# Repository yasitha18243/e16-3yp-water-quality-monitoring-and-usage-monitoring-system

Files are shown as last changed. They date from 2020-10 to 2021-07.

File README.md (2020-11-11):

# Water Quality Monitoring And Usage Management System
In this project we are developing a water tank monitoring system for providing clean water and reduce the water wastage..see our website https://cepdnaclk.github.io/e16-3yp-water-quality-monitoring-and-usage-monitoring-system/

Group No :13<br/>
E/16/049          Harshana Bandara              e16049@eng.pdn.ac.lk           
E/16/134          Yasitha Herath                e16134@eng.pdn.ac.lk                 
E/16/388          Thushara Weerasundara         e16388@eng.pdn.ac.lk   

# Problem

Water mismanagement and consumption of poluted water is a major challenge, the world is facing currently. Current market is yet to address this issue with an effective solution. The solutions that are currently present on the market are either too expensive for domestic usage or does not meet the user expectations.

# Solution

To overcome these issues, we are propossing a device which can be used to measure the water quality of the inlet of a water tank and the water level inside the tank. We expect to target both domestic user requirments and industrial user requirements by a reasonable price. User can control the device using a mobile application.

## 1.	Water quality monitoring

* TDS count – by electric conductivity of water
* Turbidity – by measuring scattering of light in water

For these 2 measurments, TDS sensors and Turbidity sensors will be used and their readings will be analyzed with ideal water quality levels and determine the water quality of the incoming water to the tank during a filling and notify the user if there is any contamination in the water. We use these 2 sensors because by using these 2 readings we can determine most of the characteristics of water.

## 2.	Water level monitoring

By using an ultrasonic sensor, water level will be monitored and when the tank is nearing to finish filling, user will be notified. We use ultrasonic sensor because of it's high accuaracy and sensor is not easily effected by water.
Also this will generate the usage reports of the water and allow user to observe the current water level in the tank if needed. This measurement also allows to rationing of water and user will be warned in case of overusage.

# Overview

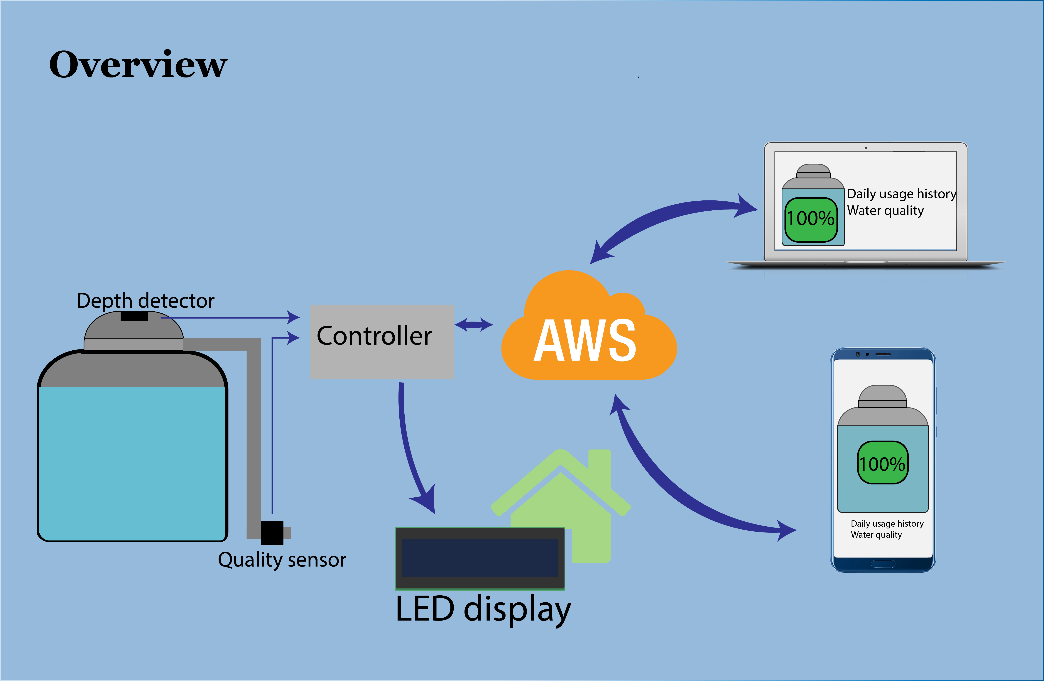
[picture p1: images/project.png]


# Technologies

* AVR       - AVR has a faster execution time than arduino. That will improve the reaction time of the device.
* Flutter   - For mobile application we expect to use Flutter because it is compatible with both ios and android platforms.
* mongoDB   - Since our device is based on cloud computing, mongoDB is the best choice for a database implementation.
* AWS       - AWS offers us higher security and also offers us with variety of IT services.

## [Introductory Video](https://github.com/cepdnaclk/e16-3yp-water-quality-monitoring-and-usage-monitoring-system/blob/main/video/Water%20Quality%20Monitoring%20and%20Usage%20Monitoring%20S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)

# Advising Lecturers

   1. Dr. Isuru Navinna
   2. Dr. Ziyan Marikkar

# [University Of Peradeniya](https://www.pdn.ac.lk/uop/directory/index.php)

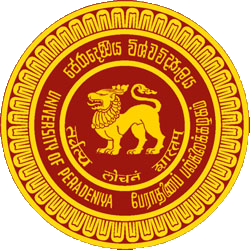
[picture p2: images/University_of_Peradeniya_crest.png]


# [Faculty Of Engineering](http://eng.pdn.ac.lk/)

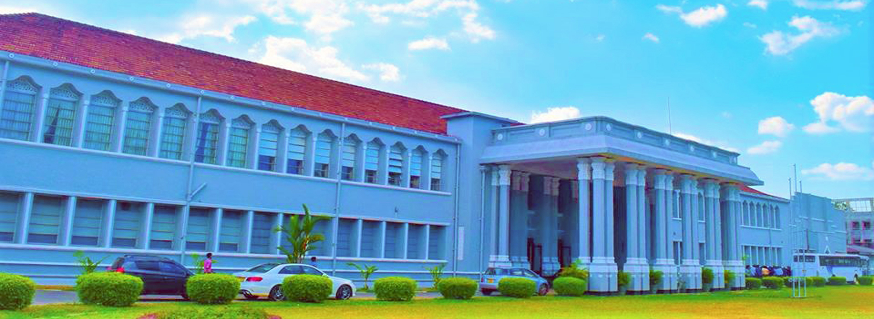
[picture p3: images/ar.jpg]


# [Department Of Computer Engineering](http://www.ce.pdn.ac.lk/)

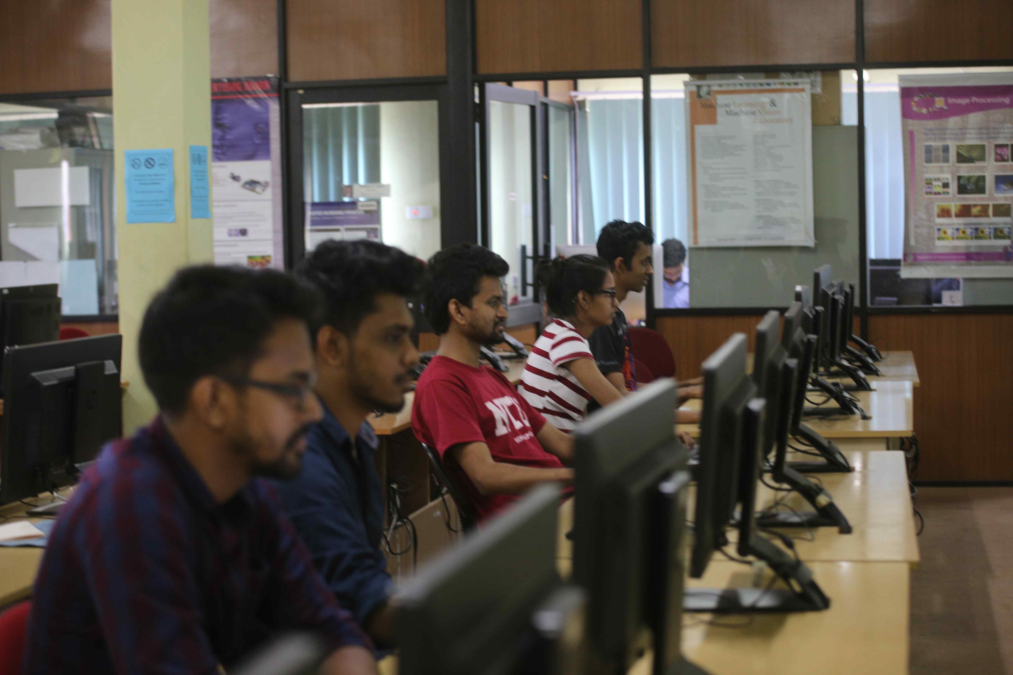
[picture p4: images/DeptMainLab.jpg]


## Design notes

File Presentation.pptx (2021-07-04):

## Water Quality Monitoring and usage monitoring System

Milestone 5 (Group 13)

E/16/049 Harshana Bandara
E/16/134 Yasitha Herath
E/16/388 Thushara Weerasundara

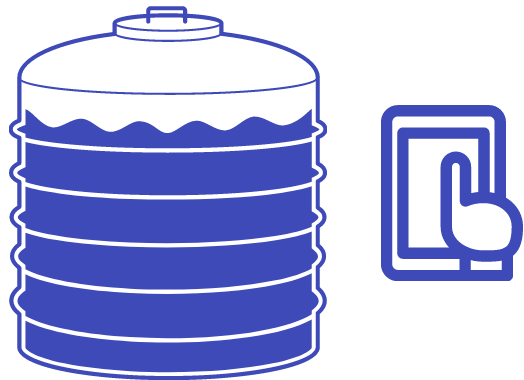
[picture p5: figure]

1

## Review

- Mointor the water level of water tanks
- Monitor the water quality of the filling water of the tanks.
- The required notifications are generated.
Consists of,
- Sensor devices
- Database
- Server

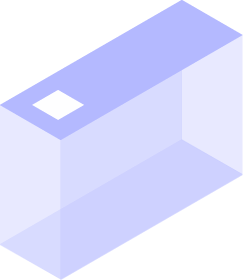
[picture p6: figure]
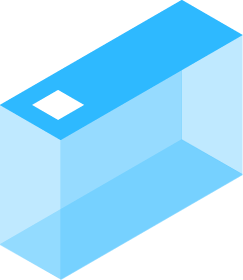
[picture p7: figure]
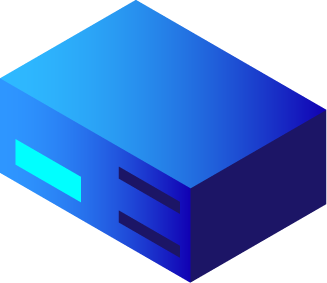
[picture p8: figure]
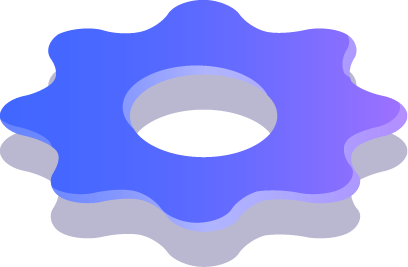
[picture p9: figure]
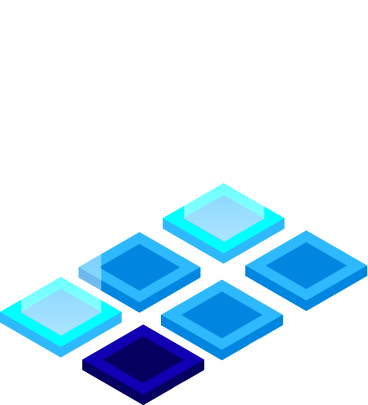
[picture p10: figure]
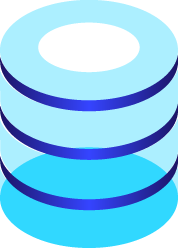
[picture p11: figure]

2

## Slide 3

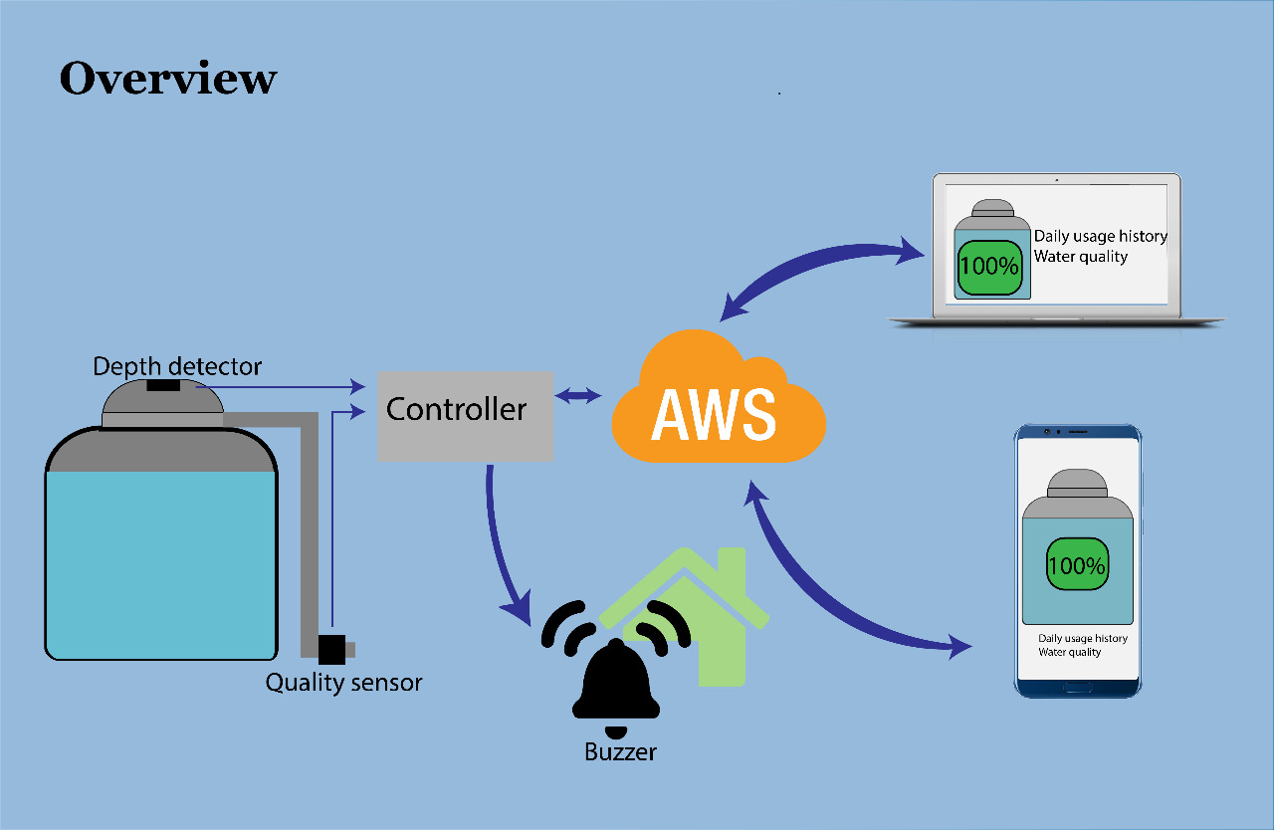
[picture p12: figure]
WhatsApp Image 2021-03-09 at 23.26.36

3

## Roles of the system

User

- Monitor Devices and Receive notifications

Admin

- Monitor the system
- Customer management and support

Super Admin

- Manage Admins

4

## Cloud Deployment

- Node js server -
EC2 instance
NGINX reverse proxy
Firewall protection
- Mongodb database
Keeping snapshots for
backup data

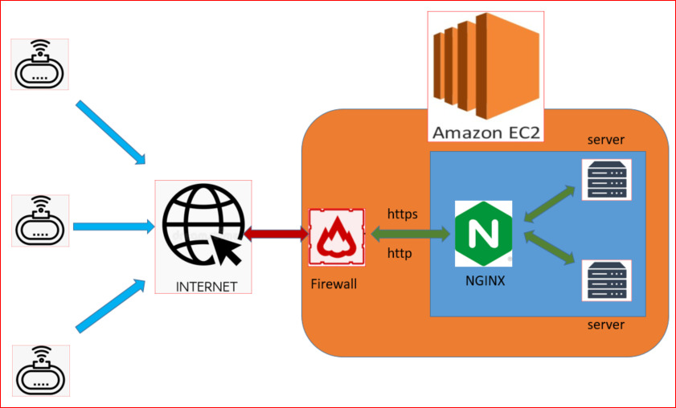
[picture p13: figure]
WhatsApp Image 2021-03-09 at 19.52.29

5

## Hardware Designs

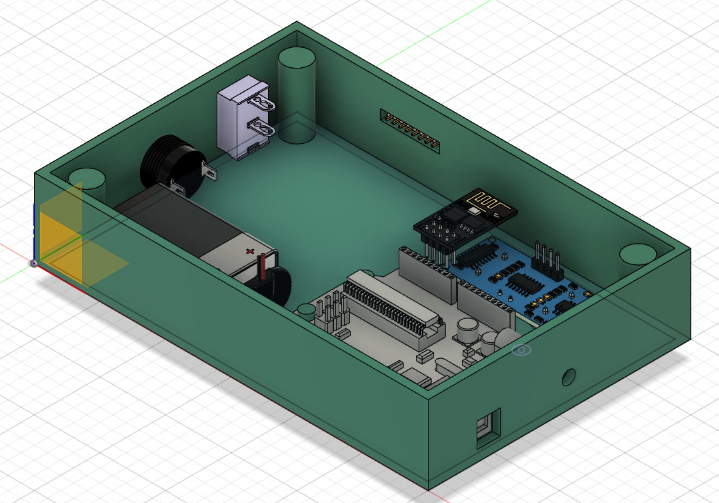
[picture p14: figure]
WhatsApp Image 2021-03-10 at 10.06.20 (1)
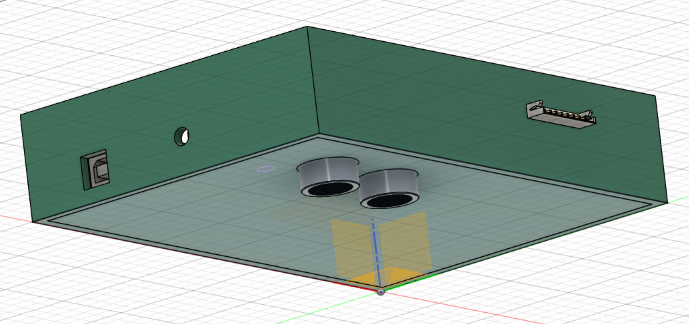
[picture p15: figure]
WhatsApp Image 2021-03-10 at 10.06.20
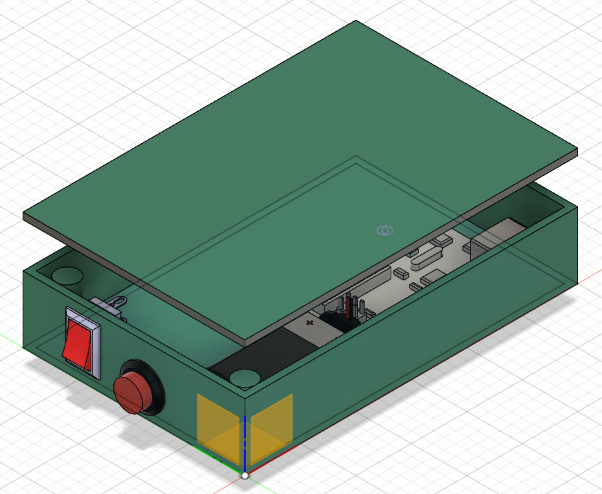
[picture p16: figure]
WhatsApp Image 2021-03-10 at 10.24.43

6

## Hardware Designs(Continue..)

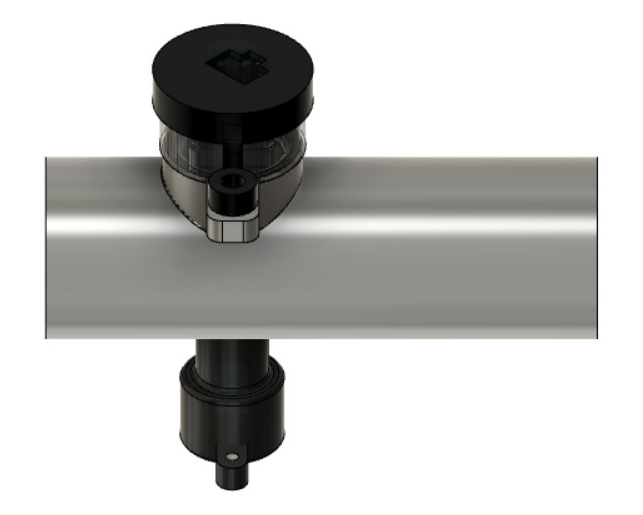
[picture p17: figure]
WhatsApp Image 2021-03-09 at 21.39.27
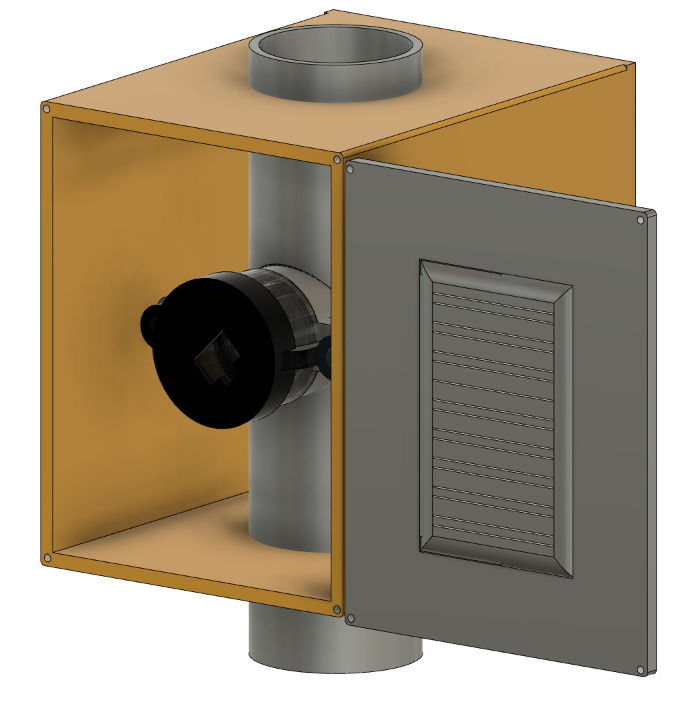
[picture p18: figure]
WhatsApp Image 2021-03-09 at 23.12.22

7

## PCB Design

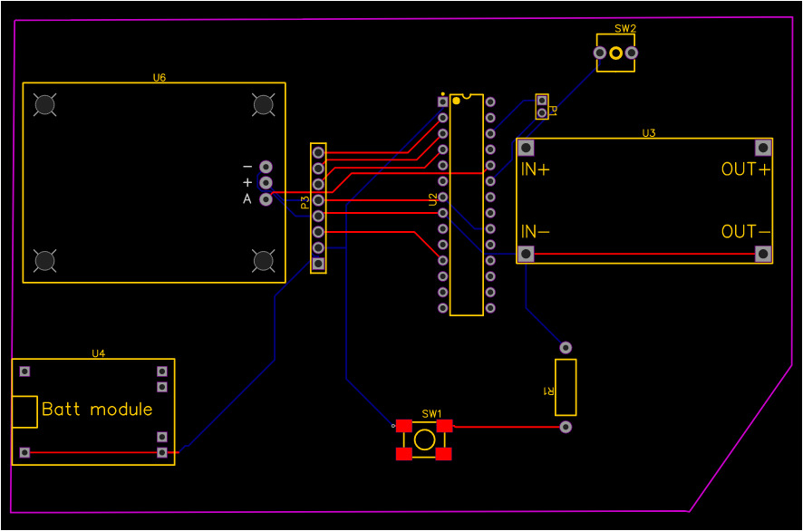
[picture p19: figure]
WhatsApp Image 2021-03-10 at 01.10.43
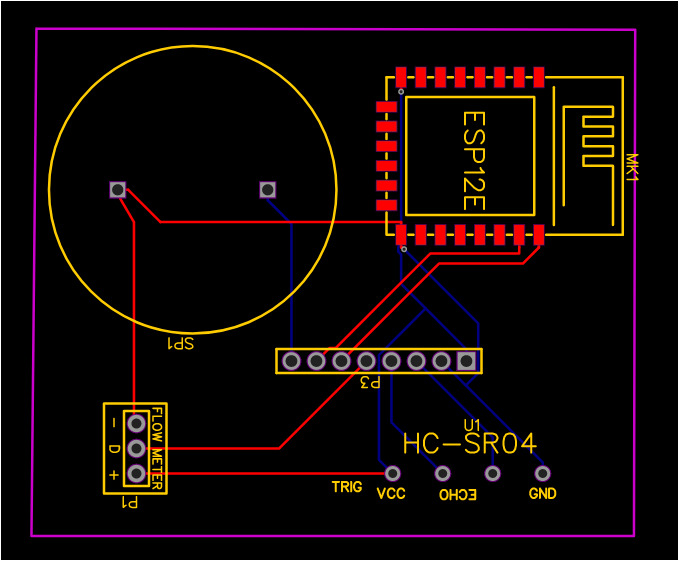
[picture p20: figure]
WhatsApp Image 2021-03-10 at 01.10.43 (1)

8

## Embedded Software

NodeMcu

- Store Device Id and WiFi information on EEPROM
- Communication with the server

ATMEGA328P

- Readings are taken by analog inputs and external inturrupts
- Setting off alarams when needed

Inter Communication

- Serial communication pins of ATMEGA328P and Software serial pins of NodeMCU

9

## User Experience

- System admins can assist the customers via website.
- Automatically notifying authorities on issues.
- Users can receive notice on upcoming water cuts.
- Device automatically get configured after installation(no tank parameters needed)

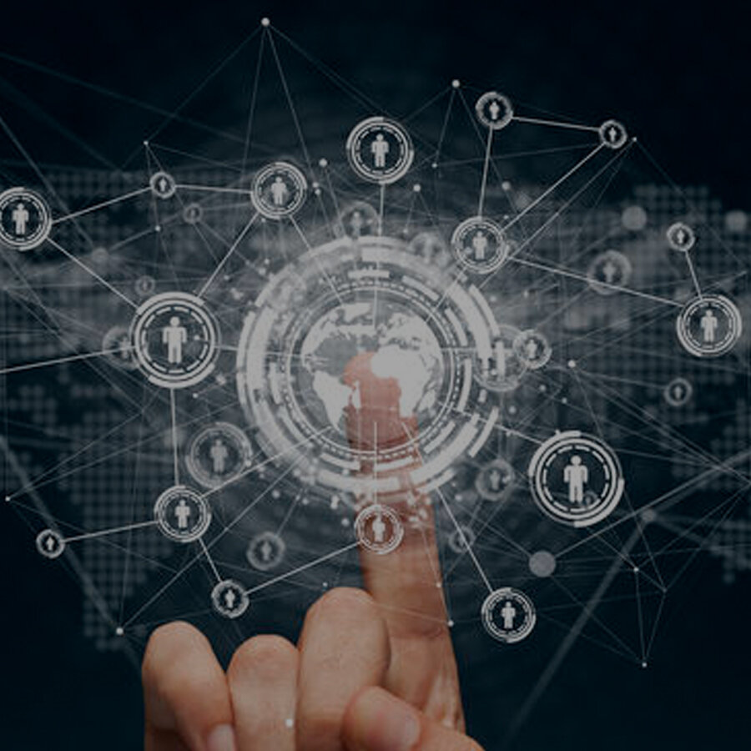
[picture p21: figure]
Cover-Square-Marketing-3

10

## Security

- Water tight design
- Non toxic material for fabrication
- Data validation

- Hardware Aspects

- Software Aspects

- Email verification on signup
- Hashing passwords using blowfish cipher
- Authorization middleware
- Setting the request rate limits

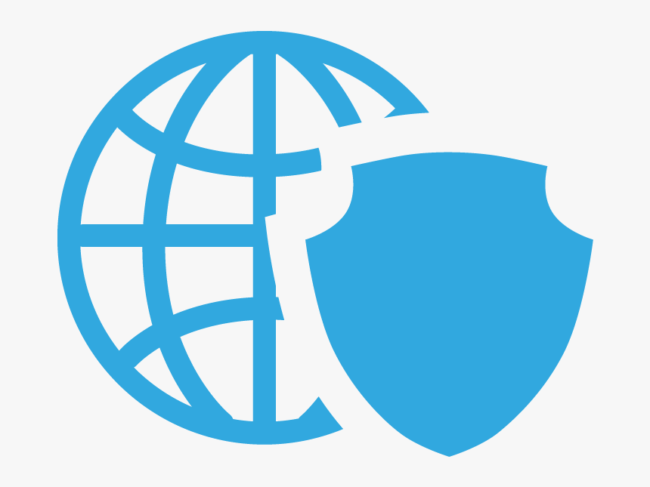
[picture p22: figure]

11

## Reliability

Scalability

Single app can monitor multiple tanks
Easy to add new devices
Can set up on any type of tank

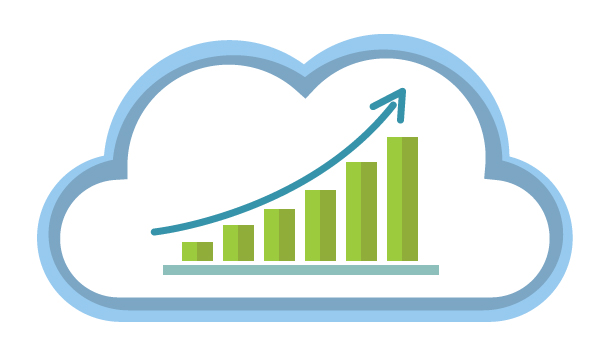
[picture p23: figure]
Tecnology-Performance1

Solar powered rechargable battery
Ability to alert the user by using a buzzer even with no wifi
Can work under extreme weather conditions
Accurate sensor readings

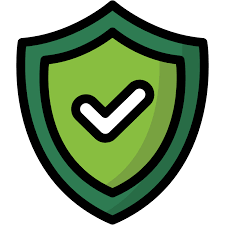
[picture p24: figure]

12

## Future Plans

- Water leakage detection functionalities
- Extend the comaptibility to other chemical types to install with chemical tanks
- Improve the app and server architecture

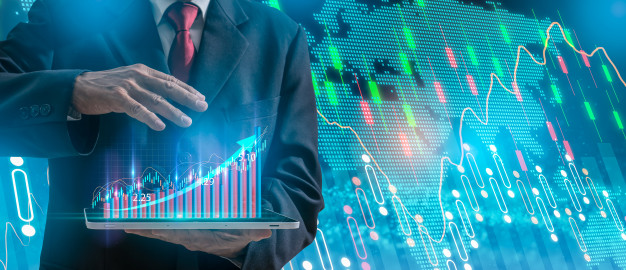
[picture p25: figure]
businessman-pointing-arrow-graph-corporate-future-growth-plan-hand-with-stock-financial-chart-symbols-coming-from-hand_34777-422

13

## Demonstration

14

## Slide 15

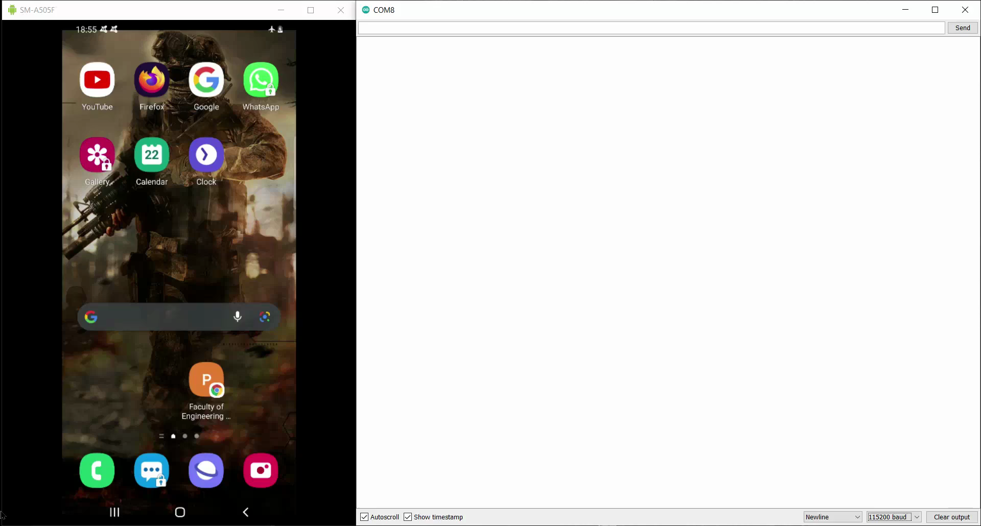
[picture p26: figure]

15

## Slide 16

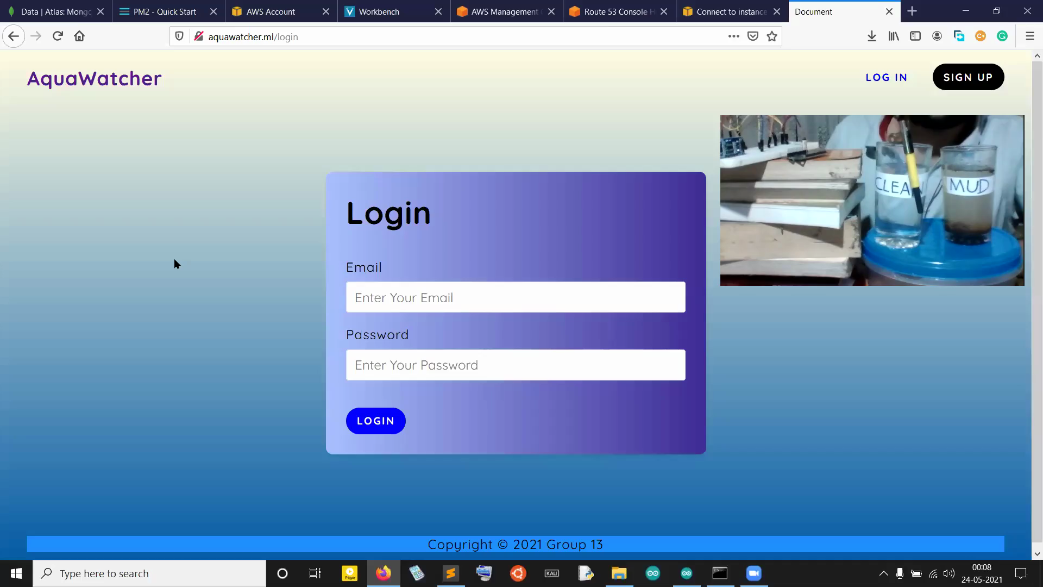
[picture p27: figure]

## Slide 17

Q & A

17

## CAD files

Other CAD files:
designs/water quality monitoring/water quality monitor.f3z
designs/water usage monitor designs/water usage monitor.f3z

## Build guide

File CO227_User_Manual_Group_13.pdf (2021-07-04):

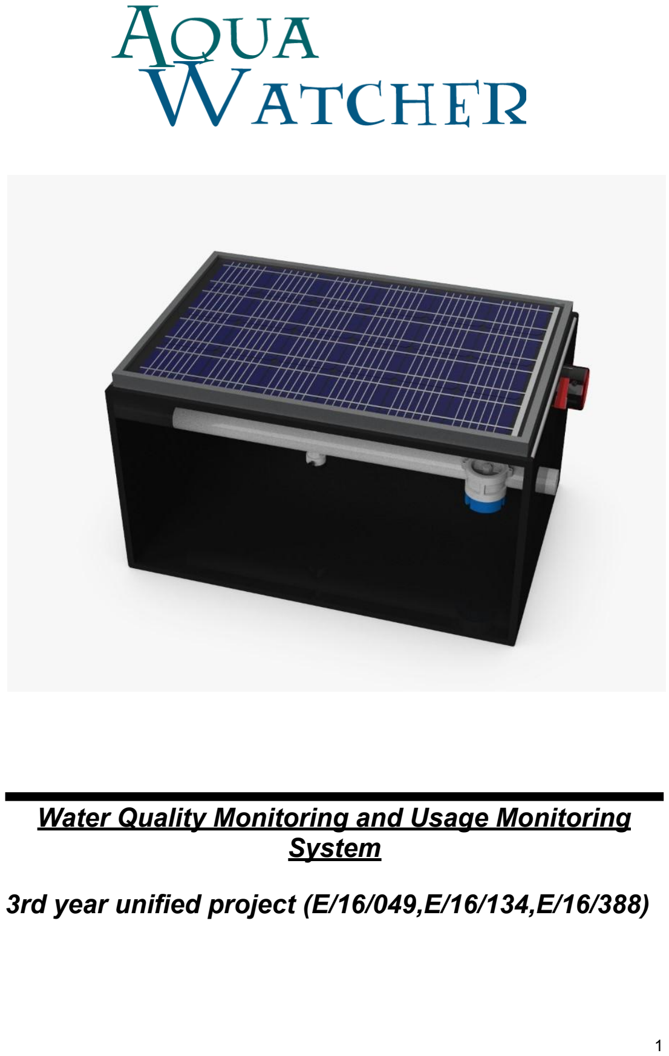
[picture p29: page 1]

## Water Quality Monitoring and Usage Monitoring System

## 3rd year unified project (E/16/049,E/16/134,E/16/388)

# User Manual

Content

5.2 Troubleshoot connecting to the Configuration server of the device .14

### 1.0 Registration for the Service

### 1.1 Contents in the box

- Water Level Monitoring Module
- Water Quality and Usage Monitoring Module
- Magnetic Knobs x 2
- Water Resistant Connector Cable
- User Guide

Water Level Monitoring Module

This device is used for water level monitoring.

View of the module to identify the power and resets switches.

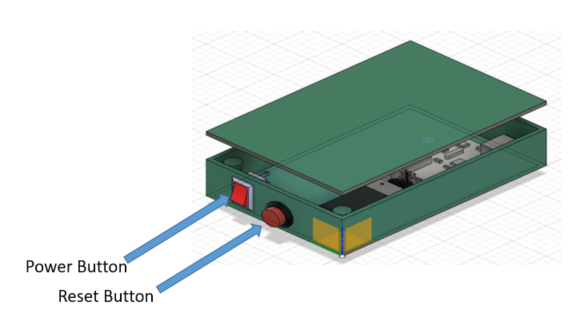
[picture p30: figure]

Water Quality and Usage Monitoring Module

This device is used for water quality monitoring.

View of the module to identify the connection to the pipes

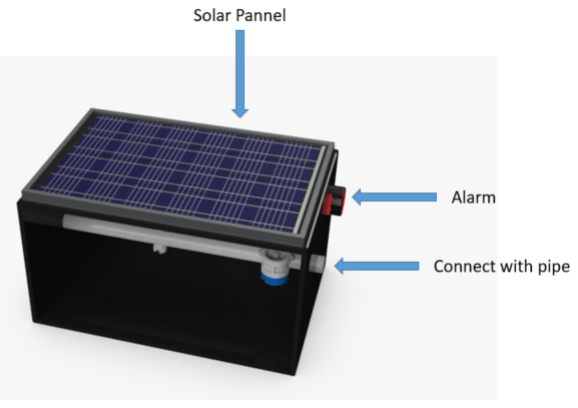
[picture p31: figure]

Magnetic Knobs

To install the Water Level Measuring Module.

Connector Cable

To interconnect the modules.

### 1.2 User Registration

### 1.2.1 What You Need Before You Begin

- WiFi internet router and an internet connection.
- Email account.
- Computer / Android / iOS supported device.

### 1.2.2 User Registration

### 1. Visit www.aquawatcher.ml website

2. Select sign up option

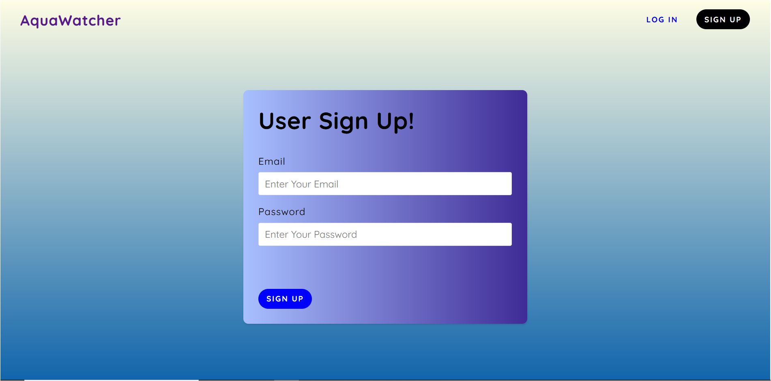
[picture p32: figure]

3. Enter your email account and a password. (Make sure email is not registered before and the password is secure)
4. Then click on the SIGN-UP button.
5. From now on you have 24 hours to complete the sign-up process, otherwise, you will have to follow the same steps as before.
6. Then you should log in to your email account and click on the verification button on the verification email to continue the Sign Up process.
7. This will verify your account and redirect you to your account.
8. Provide required information and submit to complete the registration process.

### 2.0 Device Installation

### 2.1 Water Level Monitor

1. First empty the tank.
2. Remove the closing lid.
3.Then install Water Level Monitor using 2 magnetic knobs; set 1 knob on top of the device and the other one on top of the lid. Magnetic force will hold the module. Make sure the module is levelled.
4. Close the tank.

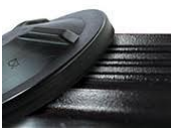
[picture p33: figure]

### 2.2 Water Quality Monitor

1.First remove the inlet of the tank.
2.Then Install the "Water Quality Monitor" to the inlet and then insert inlet pipe to the back of the device.
3.Make sure to expose the device to direct sun light if you choose to use our solar panel integrated version.

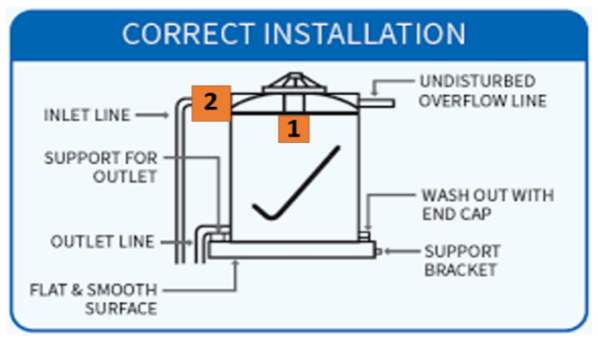
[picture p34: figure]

### 1 - Water Level Monitor 2 - Water Quality Monitor

### 3.0 Device Configuration

### 3.1 Store Device ID

1. Turn on the device.
2. Connect to AquaWatcher Device Setup! Network.
3. Go to network configuration or go to www.aqwsetup.com (http://www.aquawatcher.com) within the local network.
4. It will direct you to a web server.
5. Enter your email address and corresponding device number.
Make sure you are entering the email address you used to register to the service.

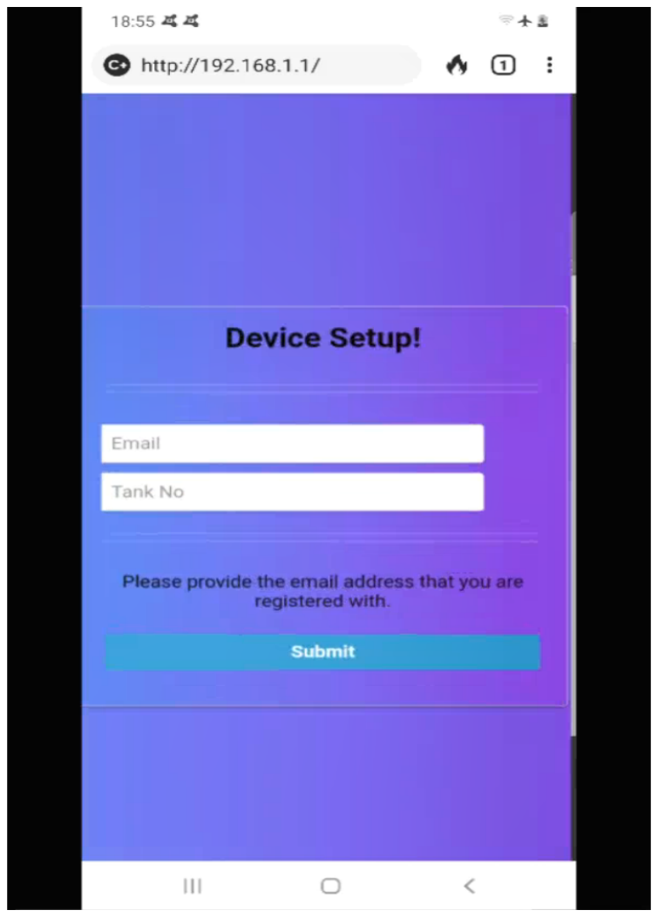
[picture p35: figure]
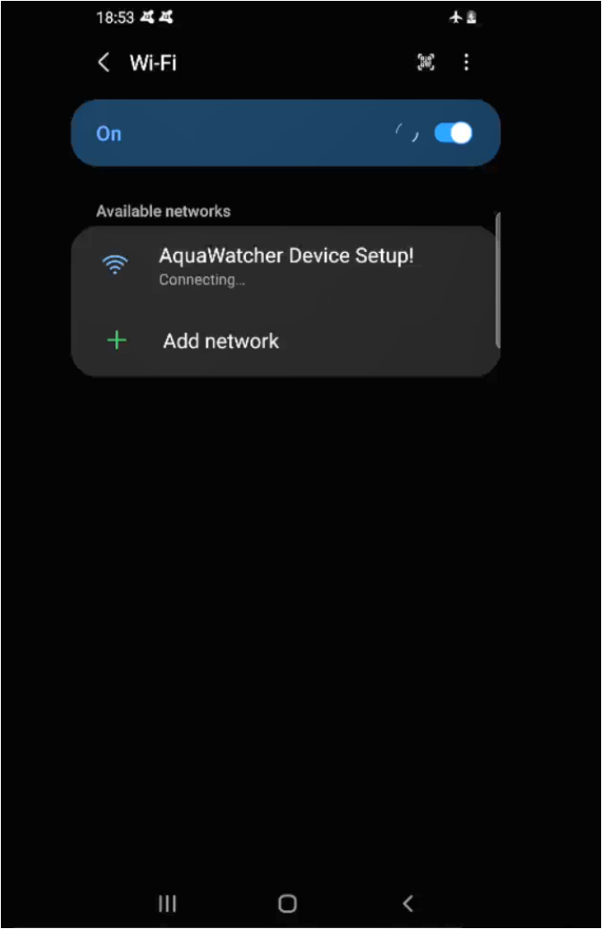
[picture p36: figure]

6. In case of resetting these values, hit the reset button and restart the process again.

### 3.2 Connect to WiFi

1. After the previous step, the device will set up another WiFi network aquawatcher.
2. Connect to it using WiFi.
3. Go to network configuration.
4. It will direct you to a web server.
5. Then select Configure WiFi
6. Enter your WiFi credentials.
7. In case the device can not access any available WiFi connection, check the WiFi information you entered.
8. To reset these values, hit the reset button and restart the process.

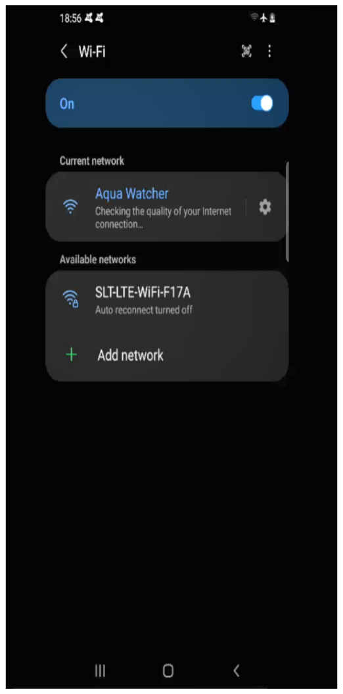
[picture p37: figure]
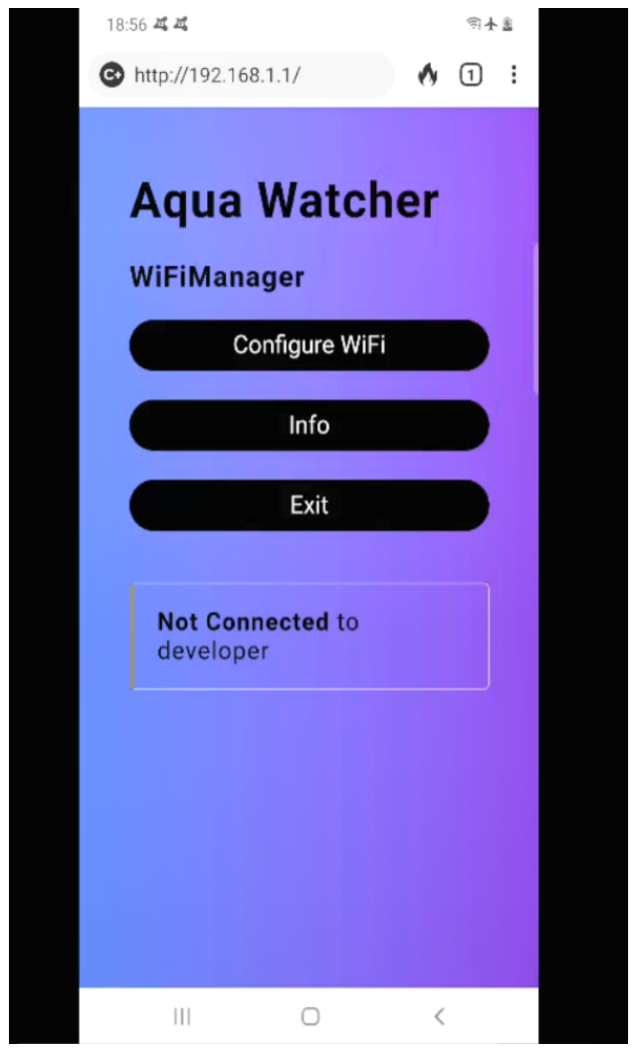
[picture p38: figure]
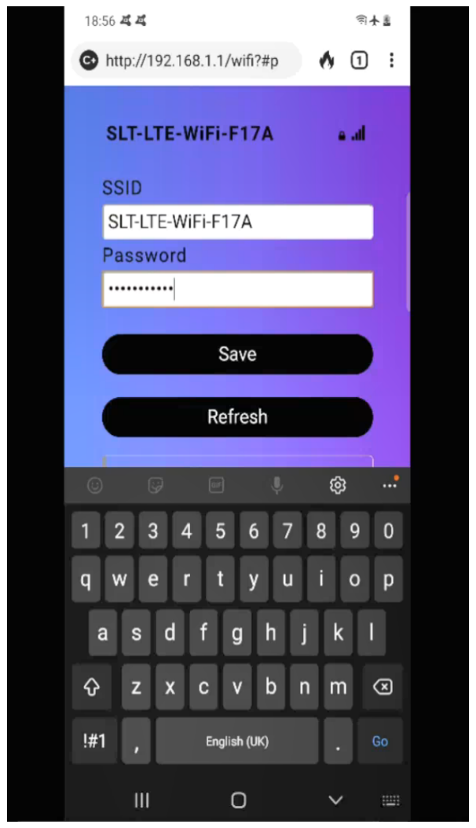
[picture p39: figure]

9. Now, the device will use your router to connect with the internet.

### 4.0 Operation

### 4.1 How to Monitor Your Devices

a) Using the Website
1. Go to our website using URL:www.aquawatcher.ml
2. Login by providing user email and password.
3. Now you can monitor your devices from here,

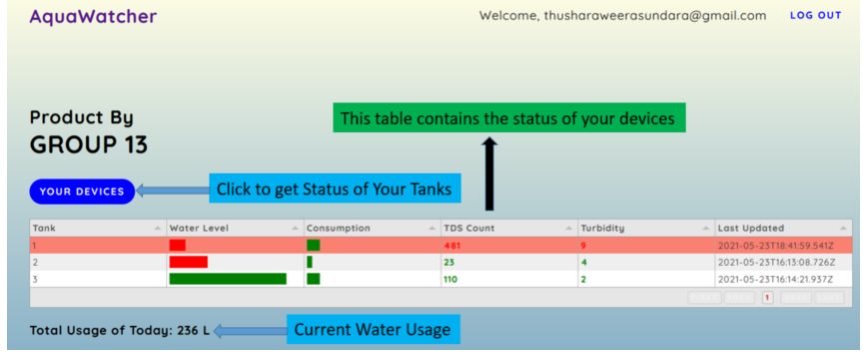
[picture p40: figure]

- Water Quality is measured as TDS and Turbidity values.
- Tanks which have contamination are highlighted in red color. Issue is in red letters.
- If the TDS count > 200 and / or Turbidity > 5 water is contaminated.
- Water Level and Usage are represented as a bar. By moving the cursor on top of them will display the actual value.
- Field “Last Updated” displayed the most recent update received by devices.
Color | Water Level | Water Usage
Red | Low | High
Yellow | Medium | Medium
Green | High | Low

4. Now you can monitor Water Usage Statistics here,

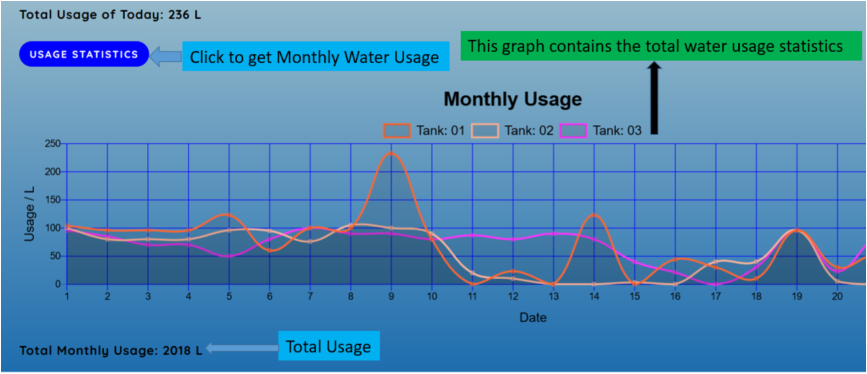
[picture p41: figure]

- Date vs Water Usage in Litres graph.
- This graph renews at 2400 hrs on the last day of the month.
- Total Usage displays the total usage of all your tanks.

b) Using the Mobile Application
- Current version (v1.1) of the mobile application is designed for delivering status about the water requirements , alerting users if there is contamination and notifying when there is special news such as water cuts. The Aquawatcher team is planning to improve the application in the future versions.
- Login Screen
- This is a simple login screen where you have to type the email address and the password you gave earlier in the registration. (Note : If you haven’t registered or verified your account , you should do it before logging in with the mobile application.)
- When you login successfully, you will access the home screen.

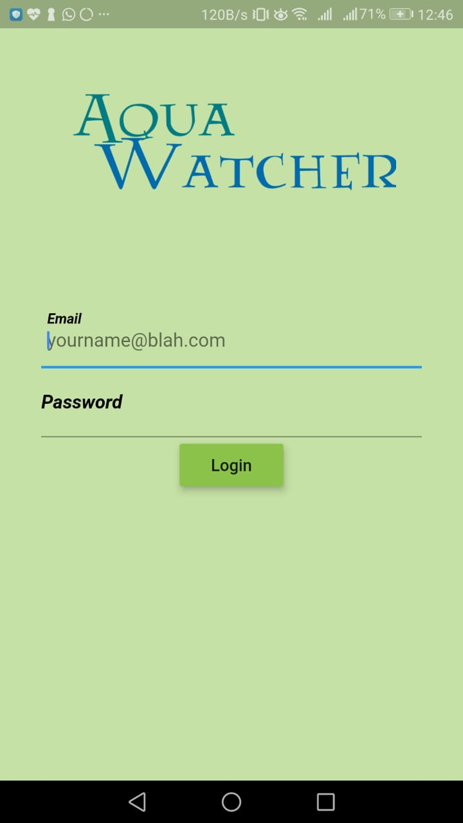
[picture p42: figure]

- Home screen
- The home screen tells the user the basic status of the tanks. If there is no contamination issue in the tanks, the home screen will say everything is ok! And if there is contamination , the home screen will change to contamination detected .
- In the home screen , you can see two buttons named your tanks and usage where you can access the respective screens.

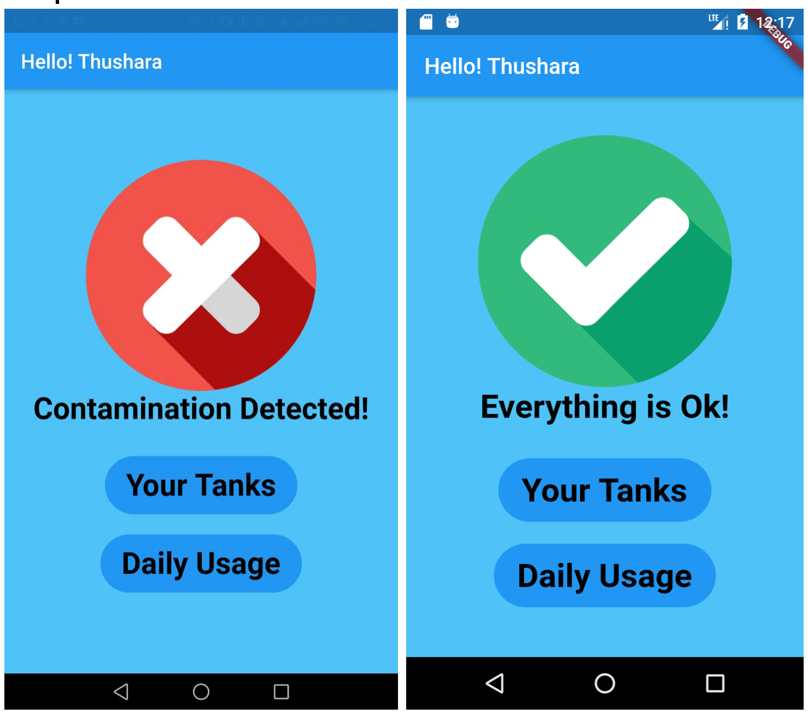
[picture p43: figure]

- Tanks screen
- In the tank screen , you will see the status of your tanks. The thumbnails represent the water level and the water quality of the tanks. Water levels are represented by the blue colour portions in the thumbnails and if there is contamination , the respective thumbnail will have a red border.
- If you touch a tank, a message will pop up which says the TDS , turbidity and the water level of the tank.

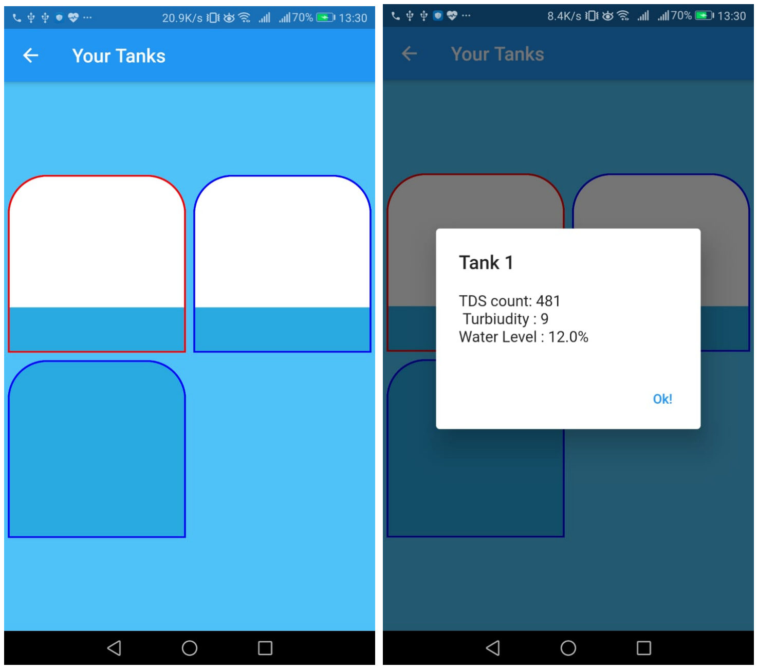
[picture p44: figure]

- Usage screen
- This screen shows the daily usages of your tanks.

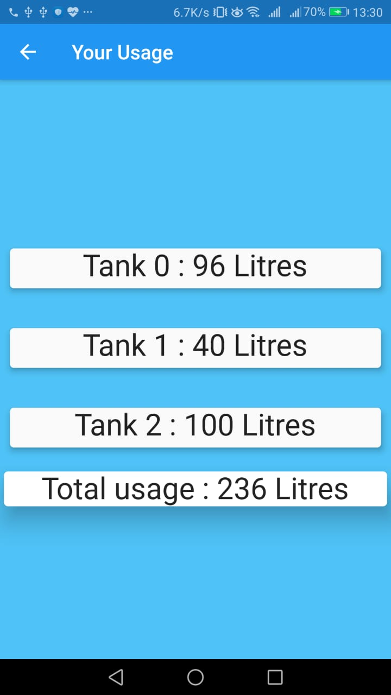
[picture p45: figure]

- Notifications and alerts
- You will get alerts when there is contamination or a water cut is scheduled by the authorities.

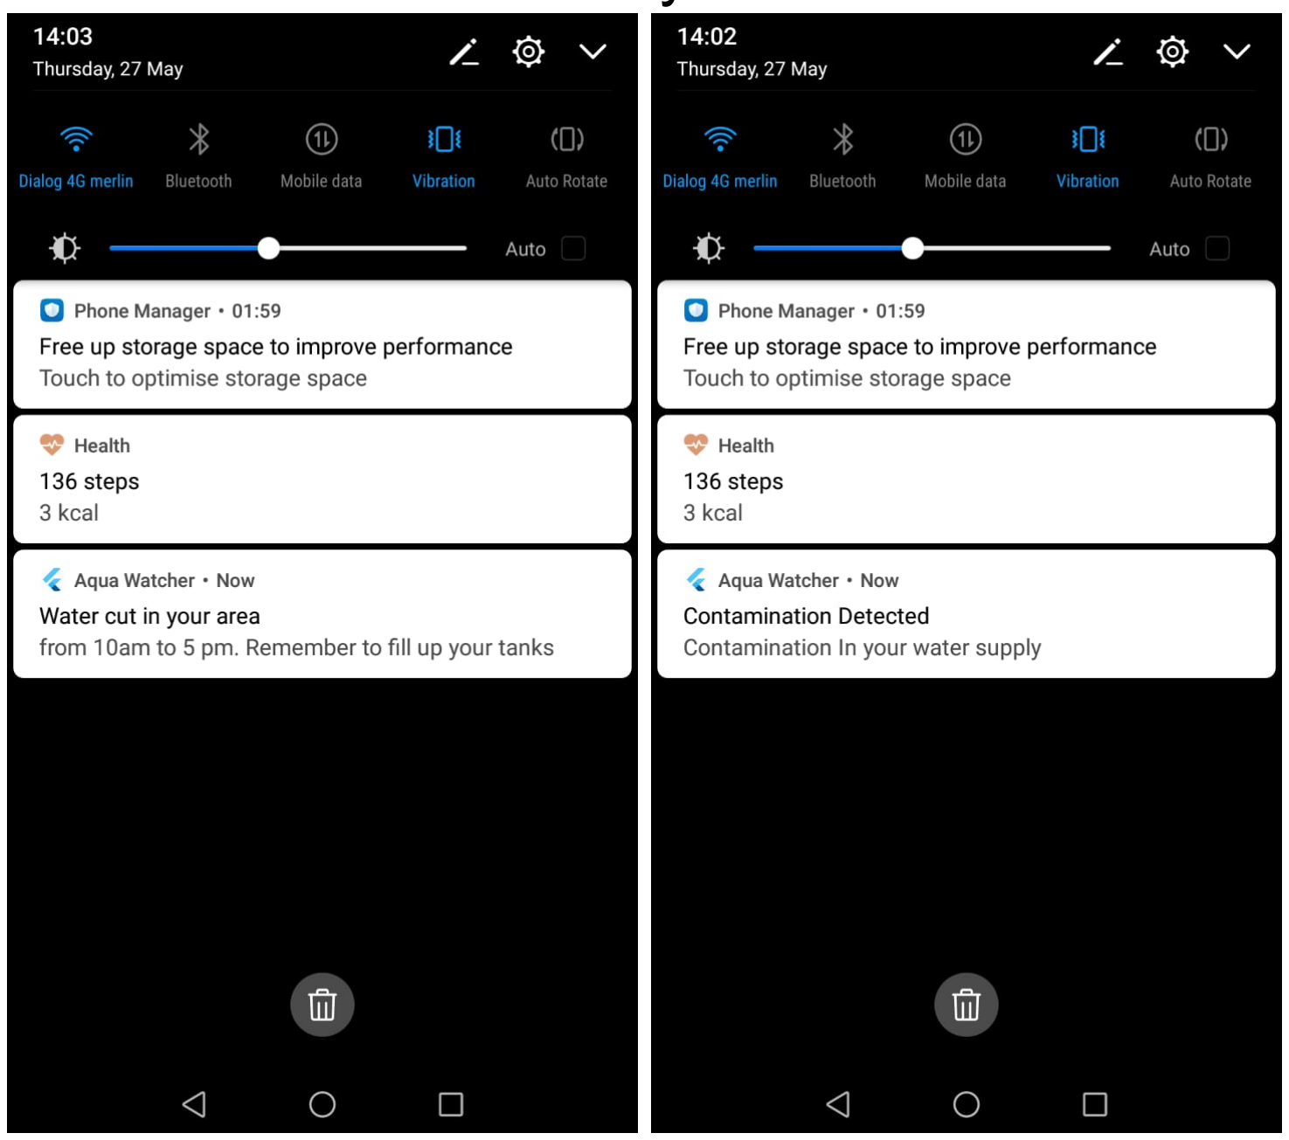
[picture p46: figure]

### 4.2 Alarms, Warnings and Notices

- On water contamination detection
- On water overflow
- On low water level
- On special announcements : ex :- pending water cuts
a) Mobile App users will directly receive the above items via the app.
b) Special announcements will be received as emails as well.
c) In case of of internet connection issue, alarm in the device will go off in in case of an emergency : ex:- contamination, overflow

### 5.0 Troubleshoot

### 5.1 Troubleshoot the hardware modules

- Make sure the cables are securely plugged in. Otherwise there will be errors in the communication between modules which leads to faulty functionality of the device. Otherwise the readings will be ignored and the new updates will not be received by the server.
- Make sure the device number and your email is entered correctly to the device.
- Make sure the Water Level Monitoring module is levelled after installation to prevent erroneous level readings.
- Make sure not to compromise the watertight covers in the modules.

### 5.2 Troubleshoot connecting to the Configuration server of the device

- If the server doesn’t start automatically, try pressing the reset button.
- If you are not automatically redirected to the server upon connecting with the network, then type www.aqwsetup.com (http://www.aquawatcher.com) on your browser. This will lead to the configuration server.
- Else, you can find the local IP address of the device in the network configuration menu and type it in your browser to access the server.

Related Links

Our Website https://cepdnaclk.github.io/e16-3yp-water-quality-monitori ng-and-usage-monitoring-system/ (https://cepdnaclk.github.io/e16-3yp-water-quality-monitoring-and-usage-monitoring-system/)

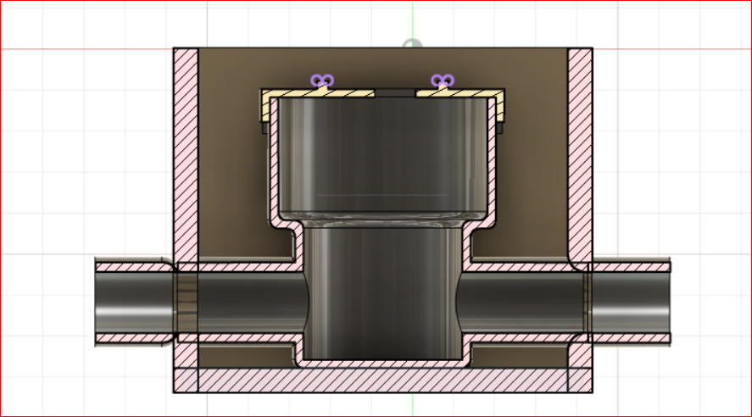
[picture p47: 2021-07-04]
designs/water usage monitor designs/3.PNG

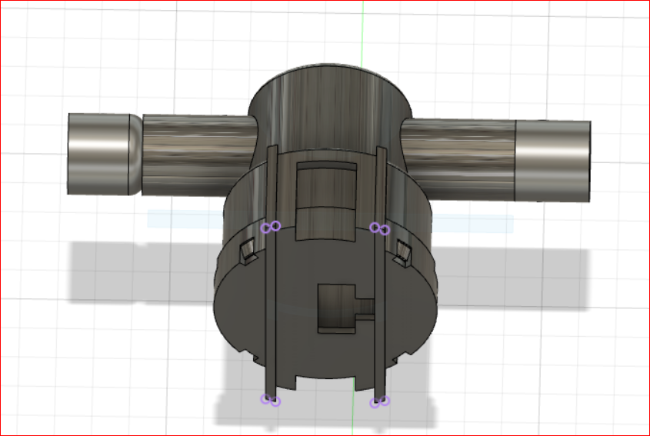
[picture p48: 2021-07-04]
designs/water usage monitor designs/1.PNG

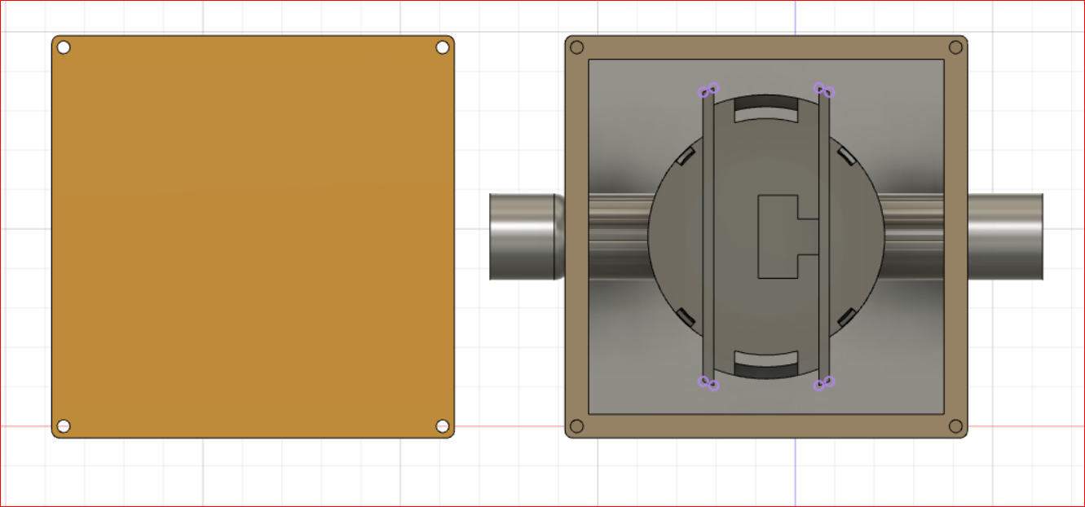
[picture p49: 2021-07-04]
designs/water usage monitor designs/2.PNG

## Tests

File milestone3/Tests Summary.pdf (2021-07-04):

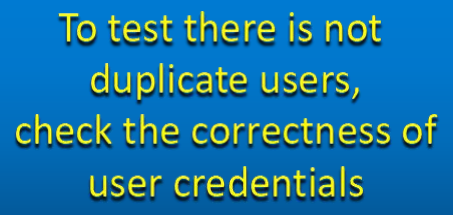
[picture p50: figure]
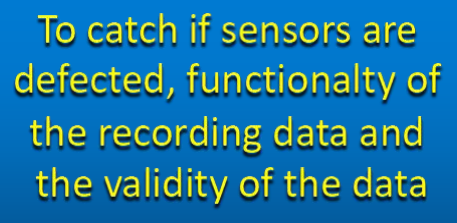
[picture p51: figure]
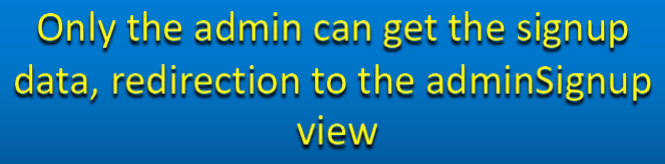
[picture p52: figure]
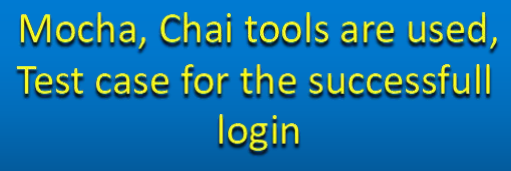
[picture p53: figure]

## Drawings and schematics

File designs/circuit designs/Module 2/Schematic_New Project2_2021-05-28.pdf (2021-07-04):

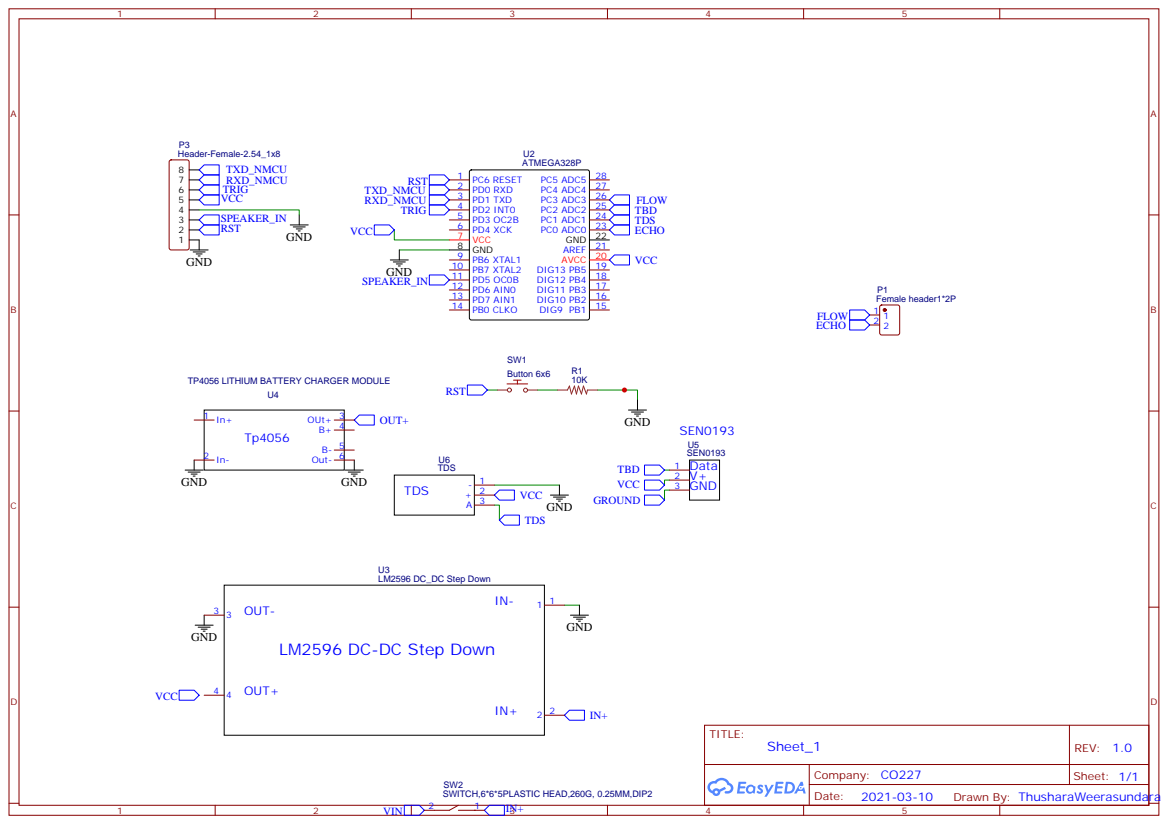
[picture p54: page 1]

TP4056 LITHIUM BATTERY CHARGER MODULE

LM2596 DC-DC Step Down

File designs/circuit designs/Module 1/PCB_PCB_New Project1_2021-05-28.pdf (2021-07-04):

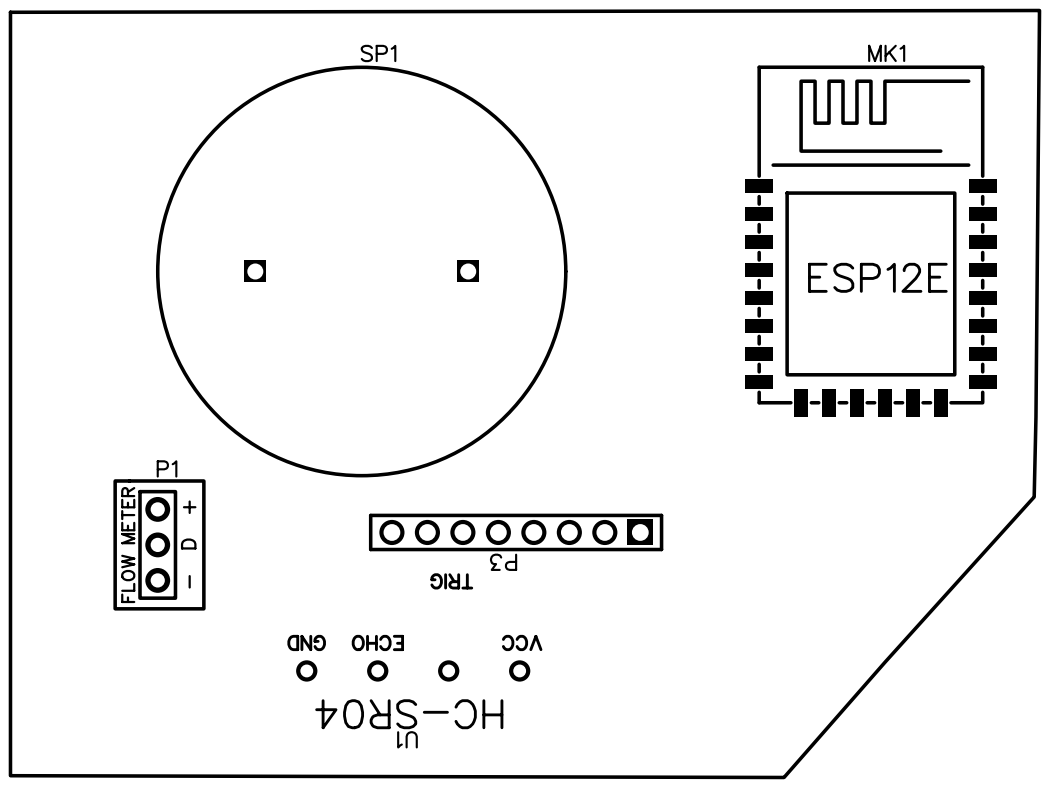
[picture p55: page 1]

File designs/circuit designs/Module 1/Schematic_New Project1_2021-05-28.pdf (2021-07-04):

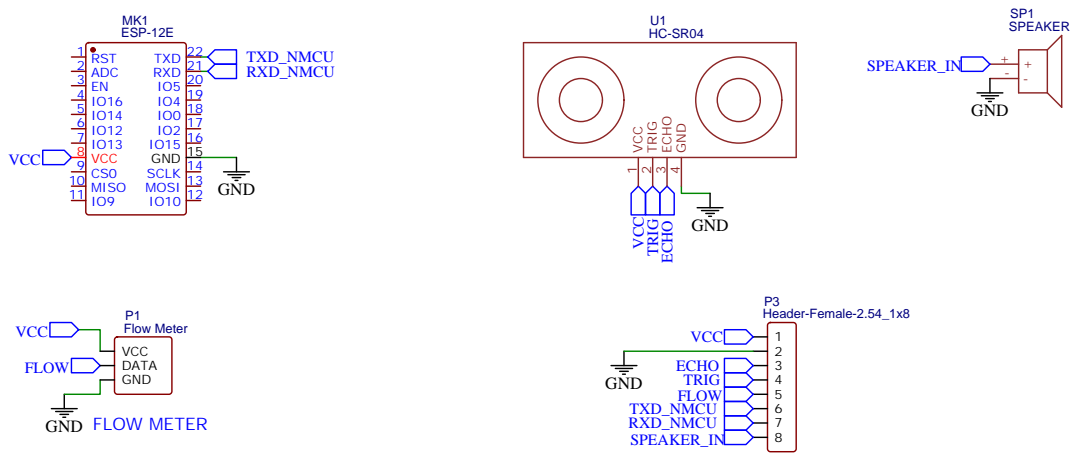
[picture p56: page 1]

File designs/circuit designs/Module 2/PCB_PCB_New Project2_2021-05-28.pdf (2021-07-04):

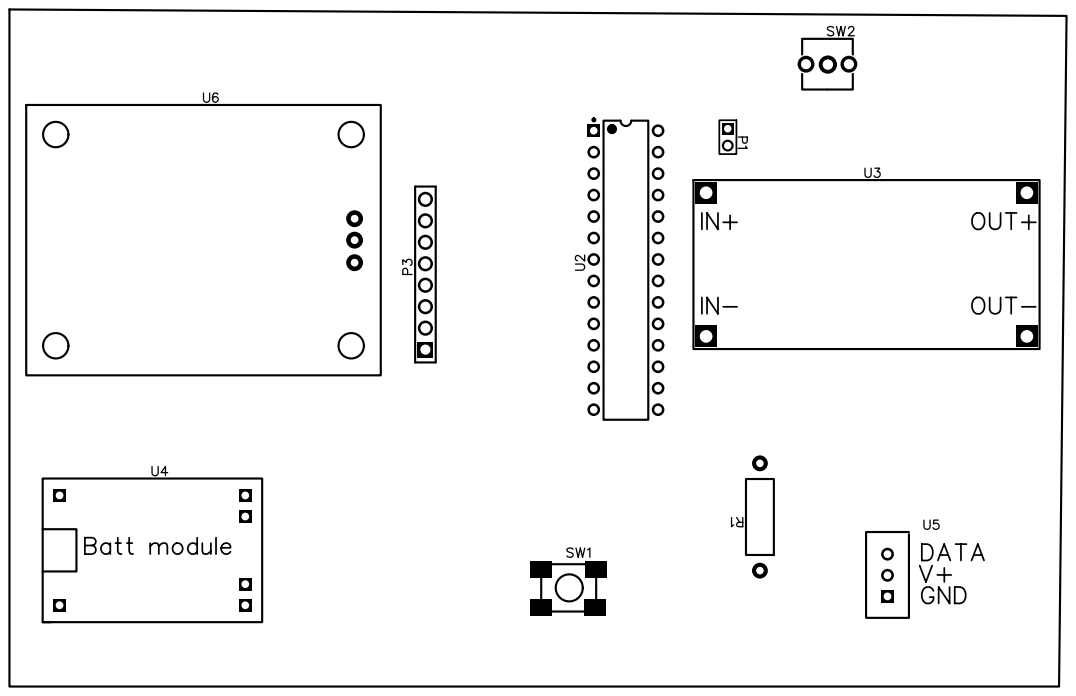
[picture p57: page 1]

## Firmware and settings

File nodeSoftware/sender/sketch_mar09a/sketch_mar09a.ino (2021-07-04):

#include <ArduinoJson.h>  

int limit = 0;

int USAGE = 0;


int readDelay = 75;

int HEIGHT = 0;

unsigned long timeNow = 0;
const unsigned long interval = 15*60*1000; // interval time

int TURBPin = A2;
int LEVELpin = A0; 
int TDSPin = A1;
int USAGEPin = 3; 
int speaker = 11;  

boolean alert = false;

int getTDS(int pin);
int getTURB(int pin);
int getLevel(int pin);


void setup()   
{
  Serial.begin(9600);
  HEIGHT = getLevel(LEVELpin);
  limit = getTDS(TDSPin);    
  attachInterrupt(USAGEPin, addL, RISING);
  pinMode(speaker, OUTPUT);
}








void loop() 
{

  if(millis() - timeNow > interval)
    {       
      timeNow = millis();
      String usage = "{\"usage\":";
      String brckt = "}";
      String volume = String(USAGE);

      String message = usage + volume + brckt;
      Serial.println(message);
      USAGE = 0;
      delay(1000);
    }

  
  int check = getTDS(TDSPin);
  int lvl = getLevel(LEVELpin);
  int tur = getTURB(TURBPin);

  String TDS = String(check);
  String TURBIDITY = String(tur);
  String LEVEL = String(lvl);

  if(lvl >= 0.9 * HEIGHT || lvl <= 0.1 * HEIGHT || check > 200 || tur > 5)
  {
    warn();
  }
  
  String tds = "{\"tds\":";
  String turbidity = ",\"turbidity\":";
  String level = ",\"level\":";
  
  String last = "}";
  
  String data =  tds + TDS + turbidity + TURBIDITY + level + LEVEL + last;
  
 
  Serial.println(data);

   
   delay(6000);
}



void addL()
{
  USAGE = USAGE + 1;
}








int getTDS(int pin)
{
 
  int total = 0;
  for(int i = 0; i < 10;  i++)
  {
    total = total + analogRead(pin);
    delay(readDelay);
  }

  return total/10;
}


int getTURB(int pin)
{
 
  int total = 0;
  for(int i = 0; i < 10;  i++)
  {
    total = total + analogRead(pin);
    delay(readDelay);
  }

  return total/10;
}


int getLevel(int pin)
{
 
  int total = 0;
  for(int i = 0; i < 10;  i++)
  {
    total = total + analogRead(pin);
    delay(readDelay);
  }

  return total/10;
}


void warn()
{
  if(!alert)
  {
    alert = true;
    tone(speaker, 700); 
  }
  else
  {
    alert = false;
    noTone(speaker);  
  }
   
}
